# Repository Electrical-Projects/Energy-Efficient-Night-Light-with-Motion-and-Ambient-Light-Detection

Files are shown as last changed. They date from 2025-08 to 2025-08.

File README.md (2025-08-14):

## Energy-Efficient Night-Light with Motion and Ambient-Light Detection
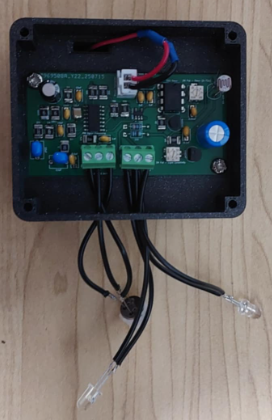
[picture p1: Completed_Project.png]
System Block Diagram


# Description
A simple and affordable motion-activated LED circuit designed for environments where activation should depend on both motion and ambient light levels. The circuit uses a PIR motion sensor and a light-dependent resistor (LDR) to allow users to define the lighting conditions under which motion will trigger the LED. Two onboard potentiometers independently adjust: (1) the environmental light threshold (from full daylight to complete darkness) and (2) the LED on-time delay (0 – 72 seconds). The design is entirely analog, requiring no microcontroller, programming, or complex setup, making it easy to replicate and modify. The circuit is open source under GNU GPL 3.0 and may be freely used, modified, and shared.

# Overview
The system operates by combining PIR motion detection with ambient light sensing. The LDR and potentiometer form an adjustable voltage divider that biases a transistor, determining whether motion detection is enabled based on current light conditions. A TLV8544 low-power comparator stage processes the sensor signals and feeds them into a SN74LVC1G00 NAND gate for signal inversion and logic control before triggering a 555 timer configured in monostable mode. The second potentiometer adjusts the RC time constant of the 555 timer, allowing precise control over the LED on-time from near-instant to over one minute.

Most of the circuit is built with through-hole components for ease of assembly, modification, and long-term serviceability. The PIR sensor section, however, is a compact, self-contained module using mostly SMD components, as it continuously processes and conditions the sensor output — a task that benefits from a smaller, integrated, and more energy-efficient layout.

A series of resistors and filtering capacitors ensure noise immunity and stable operation even in fluctuating lighting or high-EMI environments. Bulk decoupling capacitors stabilize the 6 V nominal supply for reliable performance.

Unlike microcontroller-based solutions, this analog approach offers instant startup, minimal standby current, and long-term reliability without software maintenance. Potential applications include indoor lighting control, battery-powered motion lamps, and outdoor security lights with dusk-to-dawn control.

# Assembly & Modification
All necessary PCB design files, schematics, and a complete Bill of Materials (BOM) are included. Users can order parts directly from the BOM and have the PCB fabricated using the provided Gerber files. The prototype was entirely hand-soldered, using a mix of wire solder for through-hole components and solder paste for select SMD parts in the PIR section. The board includes outputs for two LEDs, allowing for multiple lighting configurations. Since all PCB design files are provided, users are free to modify layouts, adjust footprints, or expand the design for their own applications.

# Enclosure & Use Case
An enclosure design is included, sized to house the PCB and powered by four AAA batteries. In the reference build, this enclosure was used for an indoor novelty night light, shaped like a cat ornament, where the LEDs served as the cat’s eyes

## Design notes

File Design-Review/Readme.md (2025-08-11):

# Project Review – Motion-Activated LED with Adjustable Light Sensitivity & Delay

This folder contains the full technical design review for the motion-activated LED circuit.  
The review covers the complete design process from concept to real-world use, including  
electrical design, mechanical considerations, build steps, testing methodology, and reasoning  
behind every design choice.

All materials are open source. Users can reproduce the project, adapt it to their needs,  
and modify the provided PCB and enclosure files.

---

## Table of Contents

1. [Design Overview & Specifications](01_Design-Overview-Specifications/01_design.md)

---

## How to Navigate

Each section is self-contained and can be read independently, but following them in  
order will give the most complete understanding of the project. The **Design Overview**  
dives into the TLV8544 nanopower op-amp stages, the 3.3 V regulator integration, and  
how the PIR and light-sensitivity controls interface with the delay circuitry.

---

## Related Resources

- [Electrical Design Files](../Electrical-Design)  
- [Mechanical Design Files](../Mechanical-Design)  
- [Main Project README](../README.md)

---

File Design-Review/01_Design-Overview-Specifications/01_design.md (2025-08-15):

# Design Overview & Specifications

## Overview
This board implements an **energy-efficient night light** with:
- **Motion detection** via a PIR sensor.
- **Ambient light gating** so it only triggers under desired lighting conditions.
- **Configurable on-time** using a **low-power CMOS 555** timer.
- **Two LED outputs** for flexible lighting arrangements.
- **No microcontroller** — entirely discrete and inspectable.

**Power:** 4×1.5 V - AAA Batteries (≈6 V)  
**Rails:** 6 V (LEDs only) and 3.3 V (analog front-end + logic + 555).

---

## System Block Diagram

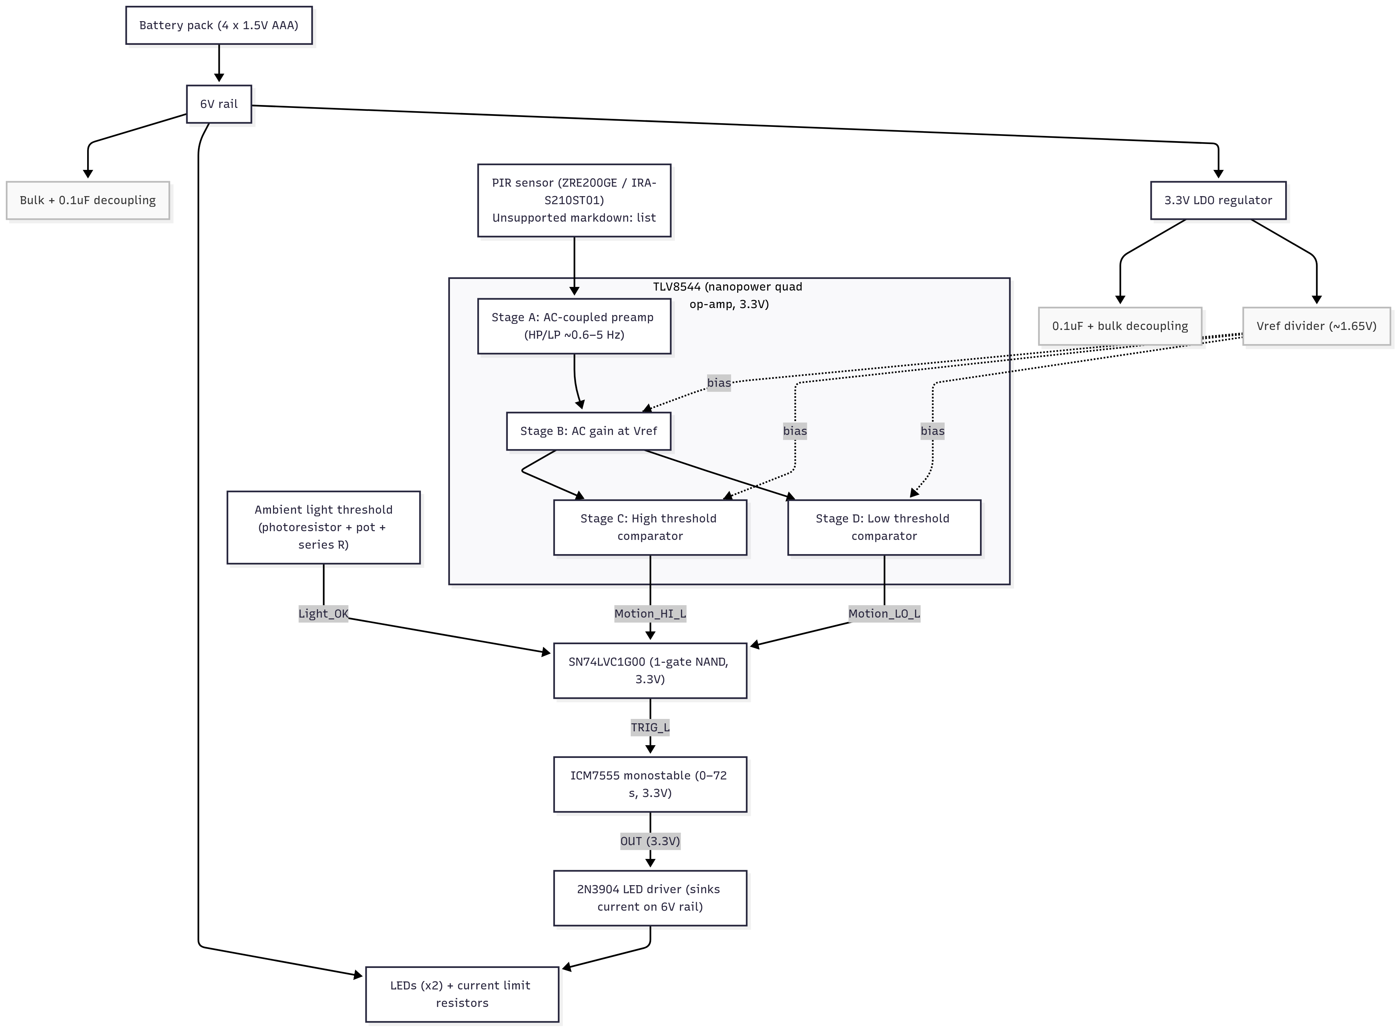
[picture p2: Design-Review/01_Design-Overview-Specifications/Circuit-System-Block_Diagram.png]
System Block Diagram


---

## Key Specifications

| Parameter | Value / Range |
|---|---|
| Supply Voltage |≈6.4 V fresh → 4.4 V depleted
| Rails | 6 V (LEDs only), 3.3 V (AFE/logic/555) |
| Quiescent Current | µA range (TLV8544 + high-value bias) |
| Motion Passband | ≈ 0.6–5 Hz |
| Ambient Light Threshold | Full daylight → full darkness |
| On-Time Range | 0–72 s (adjustable) |
| Outputs | 2× LED headers |
| PIR Lens | Round or inline Fresnel |

---

## Sensors

### PIR Sensor & Optics
- **Sensor:** Dual-element PIR (e.g., Zilog **ZRE200GE** or Murata **IRA-S210ST01**).
- **Lens:** Fresnel (inline or round) creating alternating hot/cold zones to produce AC motion signal.

### Ambient Light Sensor
- **LDR:** CdS photoresistor (e.g., **PDV-P8103**).  
  Dark ≥0.5 MΩ; ~16–33 kΩ @ 10 lux.  
- Divider with 1.5 MΩ fixed + 2 MΩ pot sets adjustable ambient-light threshold.

---

## Power Architecture

- **6 V rail (battery):** Feeds **only** the LED path and the **input** of the LDO.
- **3.3 V rail (LDO):** Feeds **TLV8544**, **ICM7555**, and logic (e.g., SN74LVC1G00).
- **Decoupling:**  
  - 6 V: bulk electrolytic near LED return + 100 nF local.  
  - 3.3 V: 10 µF + 100 nF at the LDO output, 100 nF at each IC.
- **Grounding:** Star from LDO ground; keep LED return currents off the analog ground where possible.

**Why 555 @ 3.3 V?** Lower supply spikes, guaranteed 3.3 V logic levels, and the CMOS 555 (ICM7555) maintains ultra-low supply current. Timing (`t ≈ 1.1RC`) is **independent of supply voltage**.

---

## Analog Front-End (TLV8544, Nanopower)

We use **TLV8544** — a **nanopower**, rail-to-rail quad op-amp — for the PIR chain.

### Stage A — AC Preamp & High-Pass
- Rejects the PIR’s DC output and slow thermal drifts.
- **Passband:** ~0.6–5 Hz.
- **Gain:** ×50–60 (set by feedback and input caps/resistors).

### Stage B — Second Band-Pass & Gain
- Same passband; main amplification.
- **Gain:** ~×50 (total chain ≈ ×2500–×3000).
- Mid-rail bias at **1.65 V** (½·3.3 V) from a high-value divider with local decoupling.

### Stages C & D — Window Comparator (3.3 V)
- Converts the amplified AC into a clean digital motion event.  
- Typical thresholds (vs 3.3 V mid-rail signal):  
  - **Upper:** ≈ **0.84·Vcc** ≈ **2.77 V**  
  - **Lower:** ≈ **0.16·Vcc** ≈ **0.53 V**  
- Outputs feed a small logic gate (NAND/NOR) at **3.3 V** logic level to trigger the 555.

**Why nanopower?** The TLV8544’s ultra-low input bias current (nanoamp to microamp range) minimises standby current draw, extending AAA battery life while maintaining sufficient bandwidth for human motion detection.

The following circuit diagrams illustrate two almost identical signal-processing paths:

1. Top diagram – closely matches the signal processing path implemented in this project.

2. Bottom diagram – represents a special case where the comparator op-amps are intended to be fast and “single-ended” (or “just-pull”) outputs. In this configuration, the op-amp can only source current, and an external pull-down resistor is required for sinking current.

This is not the exact three-stage circuit from the PIR sensor’s datasheet; however, both circuits are functionally very similar, with only minor implementation differences.

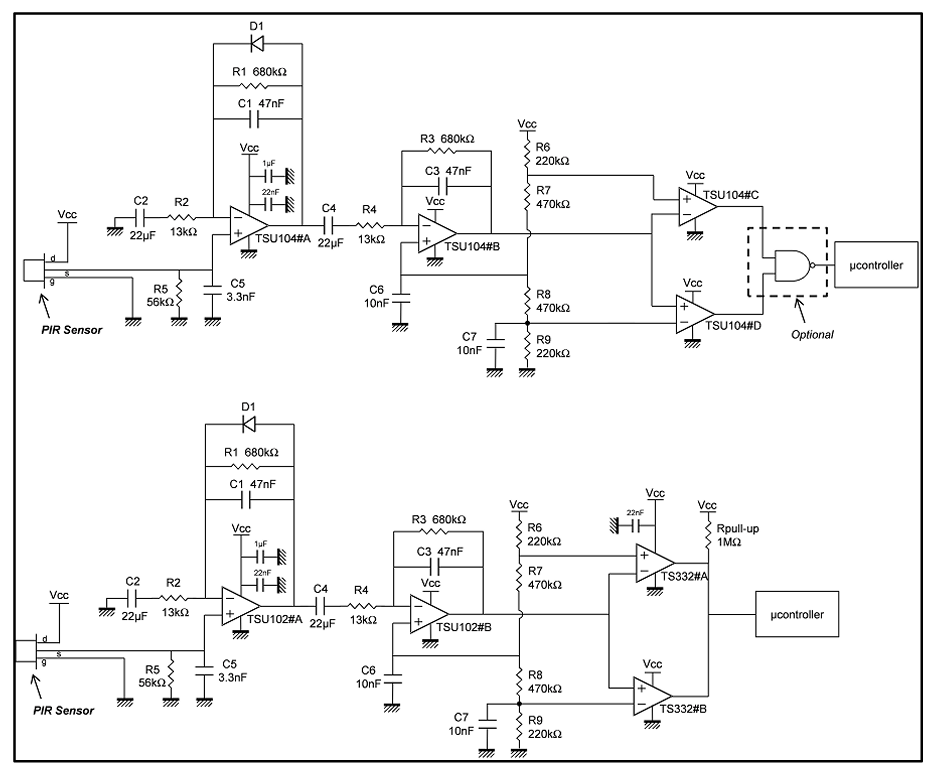
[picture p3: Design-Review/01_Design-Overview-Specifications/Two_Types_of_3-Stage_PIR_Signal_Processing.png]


---

## Ambient Light Gating (3.3 V)
- LDR + 1.5 MΩ + 2 MΩ pot create an adjustable threshold into a 3.3 V comparator/op-amp gate.  
- Motion events are **blocked** unless the ambient light matches the user-set condition (daylight to darkness).

---

## Delay Stage — ICM7555 (CMOS 555 @ 3.3 V)
- **Mode:** Monostable; triggered by motion logic from the window comparator.
- **Timing:**  
  `t_on ≈ 1.1 × R × C`  
  Example: **C = 33 µF**, **Rpot ≈ 0–2 MΩ** → **0–72 s**.
- **Notes:**  
  - Timing is largely independent of supply voltage; running at **3.3 V** improves noise behavior.  
  - Use CMOS 555 (ICM7555) for **low supply current** and **no crowbar spikes**.

The 555 output (3.3 V logic) enables the **LED driver** path that resides on the 6 V rail.

---

## LED Outputs (6 V domain)
- 2× headers with series resistors for direct LED drive from 6 V.  
- Optional low-side NPN/MOSFET if you want higher LED current or multiple LEDs per channel.
- Tie driver **logic input** to the 3.3 V 555 output through a level-safe interface if required (many FET gates are fine; check your specific transistor logic-level specs).

---

## PCB & Layout Notes
- Mostly **through-hole** for easy hand assembly.  
- **SMD** in the PIR front-end to keep high-impedance nodes short and low-noise.  
- Keep PIR input traces short, guard high-impedance nodes, and isolate LED return currents.  
- Place the LDO and 3.3 V decoupling close to the TLV8544 and 555.

---

## Adjustment & Testing
1. Power with fresh AAA cells; verify **6 V** and **3.3 V** rails.  
2. Allow **10–20 s** PIR warm-up.  
3. Set **ambient-light pot** to the desired day/night threshold.  
4. Set **delay pot** for on-time (**0–72 s**).  
5. Walk test across lens zones; confirm clean triggering and LED on-time.

---

## PCB Breakdown

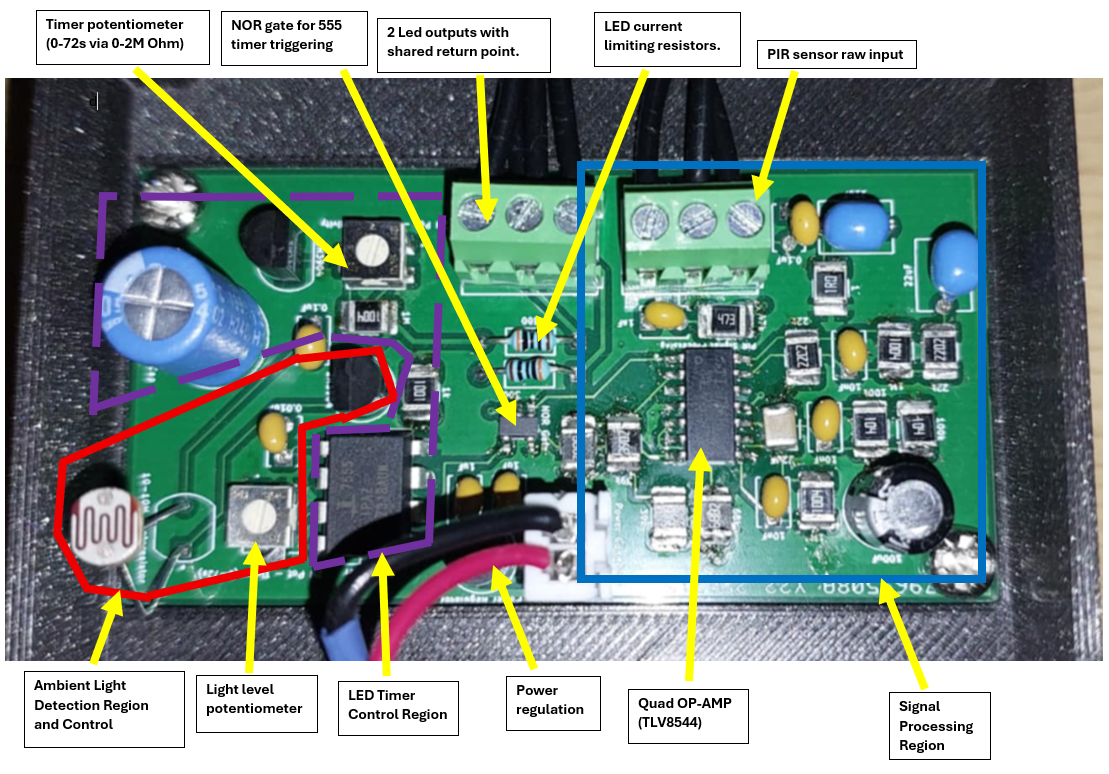
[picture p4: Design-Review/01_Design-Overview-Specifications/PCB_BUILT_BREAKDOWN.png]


---

**Related files:**  
- [Electrical Design](../../Electrical-Design/) — Schematic, BOM.  
- [Mechanical Design](../../Mechanical-Design/) — Enclosure, diffuser.

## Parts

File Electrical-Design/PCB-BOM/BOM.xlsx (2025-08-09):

Index | DigiKey Part # | Manufacturer Part Number | Manufacturer | Description | Quantity | Unit Price | Extended Price
1 | 160-1772-ND | LTW-2R3D7 | Lite-On Inc. | LED WHITE CLEAR T-1 3/4 T/H | 2 | $1.03000 | $2.06
2 | 3314J-205ECT-ND | 3314J-1-205E | Bourns Inc. | TRIMMER 2M OHM 0.25W J LEAD TOP | 2 | $2.53000 | $5.06
3 | S300CACT-ND | RNMF14FTC300R | Stackpole Electronics Inc | RES 300 OHM 1% 1/4W AXIAL | 10 | $0.06900 | $0.69
4 | 296-11597-1-ND | SN74LVC1G02DBVR | Texas Instruments | IC GATE NOR 1CH 2-INP SOT23-5 | 10 | $0.10700 | $1.07
5 | P14480-ND | EEA-GA1A101 | Panasonic Electronic Components | CAP ALUM 100UF 20% 10V RADIAL TH | 3 | $0.51000 | $1.53
6 | 2N3904FS-ND | 2N3904BU | onsemi | TRANS NPN 40V 0.2A TO-92-3 | 3 | $0.45000 | $1.35
7 | 13-RC1210JR-07100KLCT-ND | RC1210JR-07100KL | YAGEO | RES 100K OHM 5% 1/2W 1210 | 10 | $0.05600 | $0.56
8 | 732-2748-ND | 691214110003 | Würth Elektronik | TERM BLK 3POS SIDE ENT 3.5MM PCB | 2 | $1.70000 | $3.40
9 | 490-11915-ND | IRA-S210ST01 | Murata Electronics | MOTION SENSOR | 1 | $3.48000 | $3.48
10 | 490-12568-ND | IML-0685 | Murata Electronics | LENS FOR IRA-S210ST01 | 1 | $4.79000 | $4.79
11 | ICM7555IPAZ-ND | ICM7555IPAZ | Renesas Electronics Corporation | IC OSC SINGLE TIMER 1MHZ 8DIP | 2 | $1.15000 | $2.30
12 | UBW1H330MPD-ND | UBW1H330MPD | Nichicon | CAP ALUM 33UF 20% 50V RADIAL TH | 2 | $1.38000 | $2.76
13 | PDV-P8103-ND | PDV-P8103 | Advanced Photonix | CDS PHOTORESISTOR 16-33KOHM | 1 | $1.12000 | $1.12
14 | 455-B2B-XH-A-ND | B2B-XH-A | JST Sales America Inc. | CONN HEADER VERT 2POS 2.5MM | 2 | $0.16000 | $0.32
15 | 296-51820-1-ND | TLV8544DR | Texas Instruments | IC OPAMP GP 4 CIRCUIT 14SOIC | 2 | $2.35000 | $4.70
16 | 445-173294-1-ND | FG20X7R1C226MRT06 | TDK Corporation | CAP CER 22UF 16V X7R RADIAL | 2 | $1.39000 | $2.78
17 | MCP1702-3302E/TO-ND | MCP1702-3302E/TO | Microchip Technology | IC REG LINEAR 3.3V 250MA TO92-3 | 2 | $1.04000 | $2.08
18 | YAG2296CT-ND | RC1210FR-071KL | YAGEO | RES 1K OHM 1% 1/2W 1210 | 10 | $0.04800 | $0.48
19 | 13-RC1210JR-0747KLCT-ND | RC1210JR-0747KL | YAGEO | RES 47K OHM 5% 1/2W 1210 | 10 | $0.05800 | $0.58
20 | 13-RC1210FR-071MLCT-ND | RC1210FR-071ML | YAGEO | RES 1M OHM 1% 1/2W 1210 | 10 | $0.05100 | $0.51
21 | RMCF1210JT1R00CT-ND | RMCF1210JT1R00 | Stackpole Electronics Inc | RES 1 OHM 5% 1/2W 1210 | 10 | $0.09100 | $0.91
22 | 13-RC1210FR-0722KLCT-ND | RC1210FR-0722KL | YAGEO | RES 22K OHM 1% 1/2W 1210 | 10 | $0.06700 | $0.67
23 | 13-RC1210FR-0739KLCT-ND | RC1210FR-0739KL | YAGEO | RES 39K OHM 1% 1/2W 1210 | 10 | $0.11200 | $1.12
24 | A129893CT-ND | CRGCQ1210F68K | TE Connectivity Passive Product | RES 68K OHM 1% 1/2W 1210 | 10 | $0.18700 | $1.87
25 | 399-13907-1-ND | C315C103K1R5TA7303 | KEMET | CAP CER 10000PF 100V X7R RADIAL | 3 | $1.39000 | $4.17
26 | 399-C318C104Z5U5TA-ND | C318C104Z5U5TA | KEMET | CAP CER 0.1UF 50V Z5U RADIAL | 10 | $0.25500 | $2.55
27 | 399-9714-ND | C315C105K3R5TA | KEMET | CAP CER 1UF 25V X7R RADIAL | 3 | $1.46000 | $4.38
28 | 399-4144-ND | C315C102K1R5TA | KEMET | CAP CER 1000PF 100V X7R RADIAL | 5 | $0.48000 | $2.40
29 | 1276-1851-1-ND | CL32A226MOJNNNE | Samsung Electro-Mechanics | CAP CER 22UF 16V X5R 1210 | 2 | $0.56000 | $1.12
30 | 490-10535-1-ND | GRM32NC81C226KE15L | Murata Electronics | CAP CER 22UF 16V X6S 1210 | 1 | $1.81000 | $1.81

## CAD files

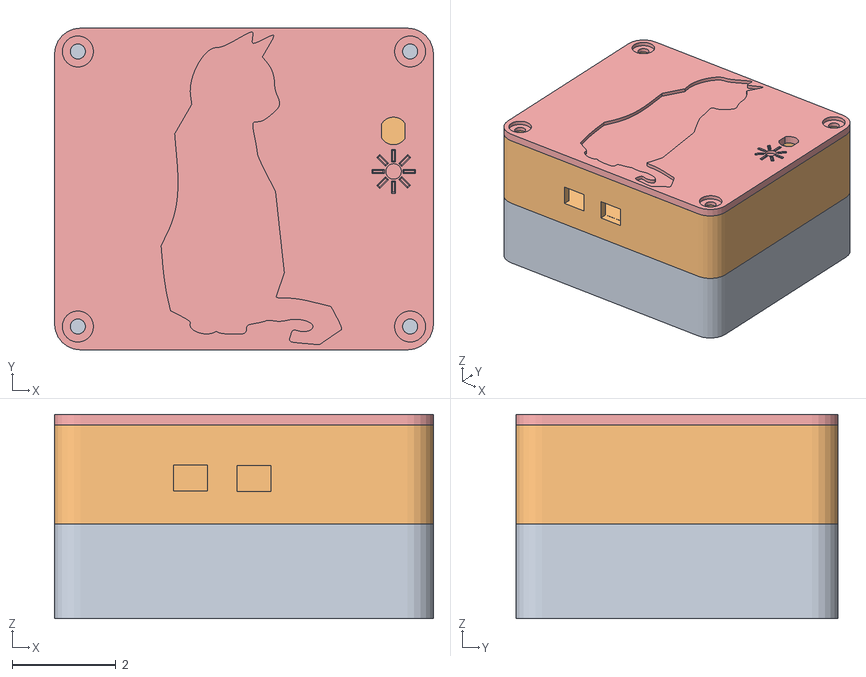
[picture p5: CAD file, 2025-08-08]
Mechanical-Design/Electronics-Enclosure/3D-Enclosure-Models/Night Light Electronics Enclosure_.obj
7.29 x 6.19 x 3.92
Enclosure Base
Enclosure Top
Battery Case Holder
Battery Lid
Enclosure Lid

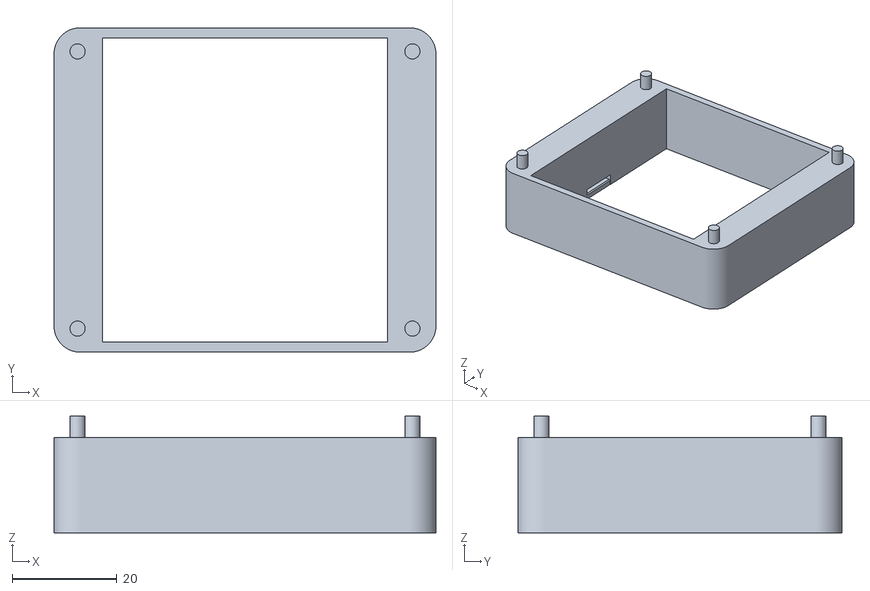
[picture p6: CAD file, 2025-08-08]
Mechanical-Design/Electronics-Enclosure/3D-Printable-STLs/Enclosure Bulk Base.stl
72.9 x 61.9 x 22.3

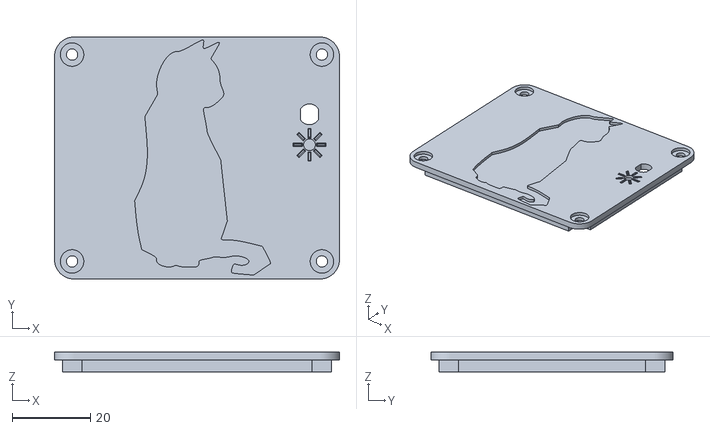
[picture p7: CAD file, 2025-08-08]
Mechanical-Design/Electronics-Enclosure/3D-Printable-STLs/Night Light Electronics Enclosure - LID.stl
72.9 x 61.9 x 5.00

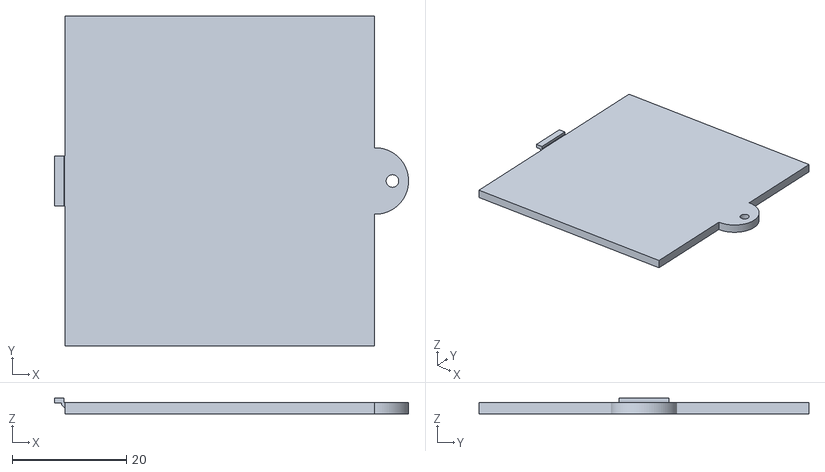
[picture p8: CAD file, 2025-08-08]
Mechanical-Design/Electronics-Enclosure/3D-Printable-STLs/Enclosure Battery Lid.stl
62.0 x 57.7 x 2.75

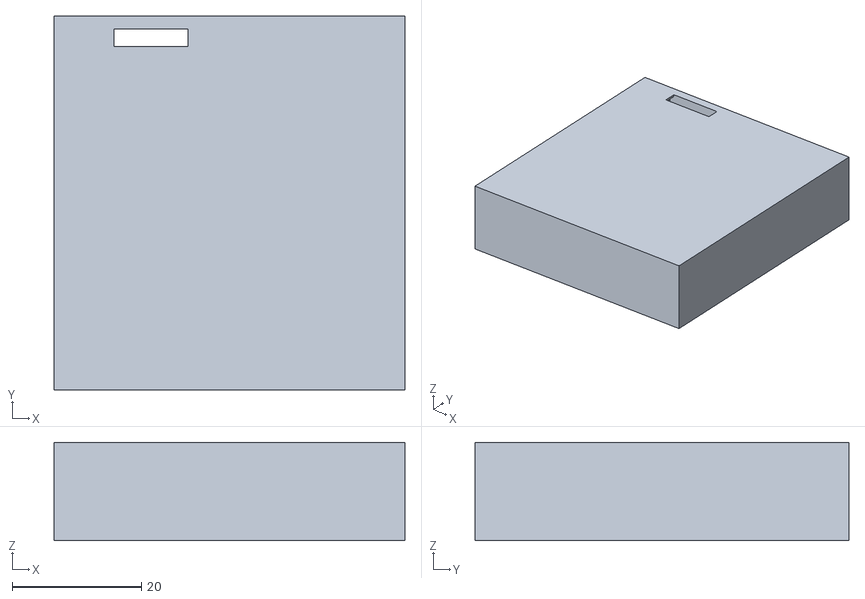
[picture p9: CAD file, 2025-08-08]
Mechanical-Design/Electronics-Enclosure/3D-Printable-STLs/4xAAA Battery Case Holder.stl
54.3 x 57.9 x 15.2

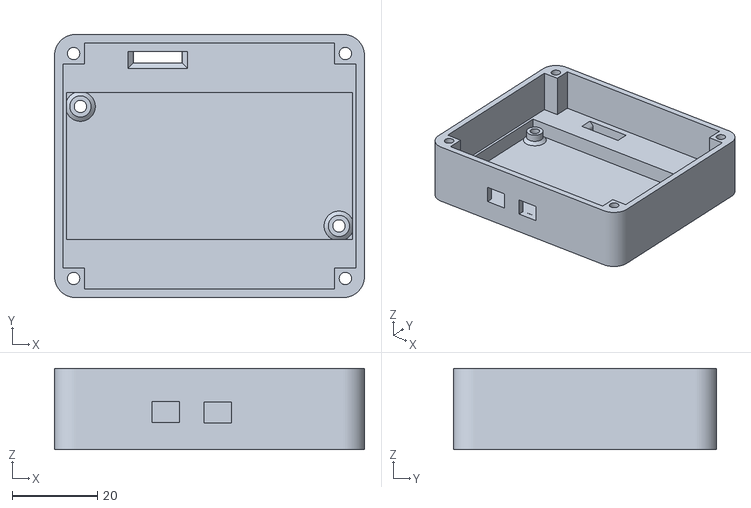
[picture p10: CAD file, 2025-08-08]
Mechanical-Design/Electronics-Enclosure/3D-Printable-STLs/Enclosure Bulk Top.stl
72.9 x 61.9 x 19.0

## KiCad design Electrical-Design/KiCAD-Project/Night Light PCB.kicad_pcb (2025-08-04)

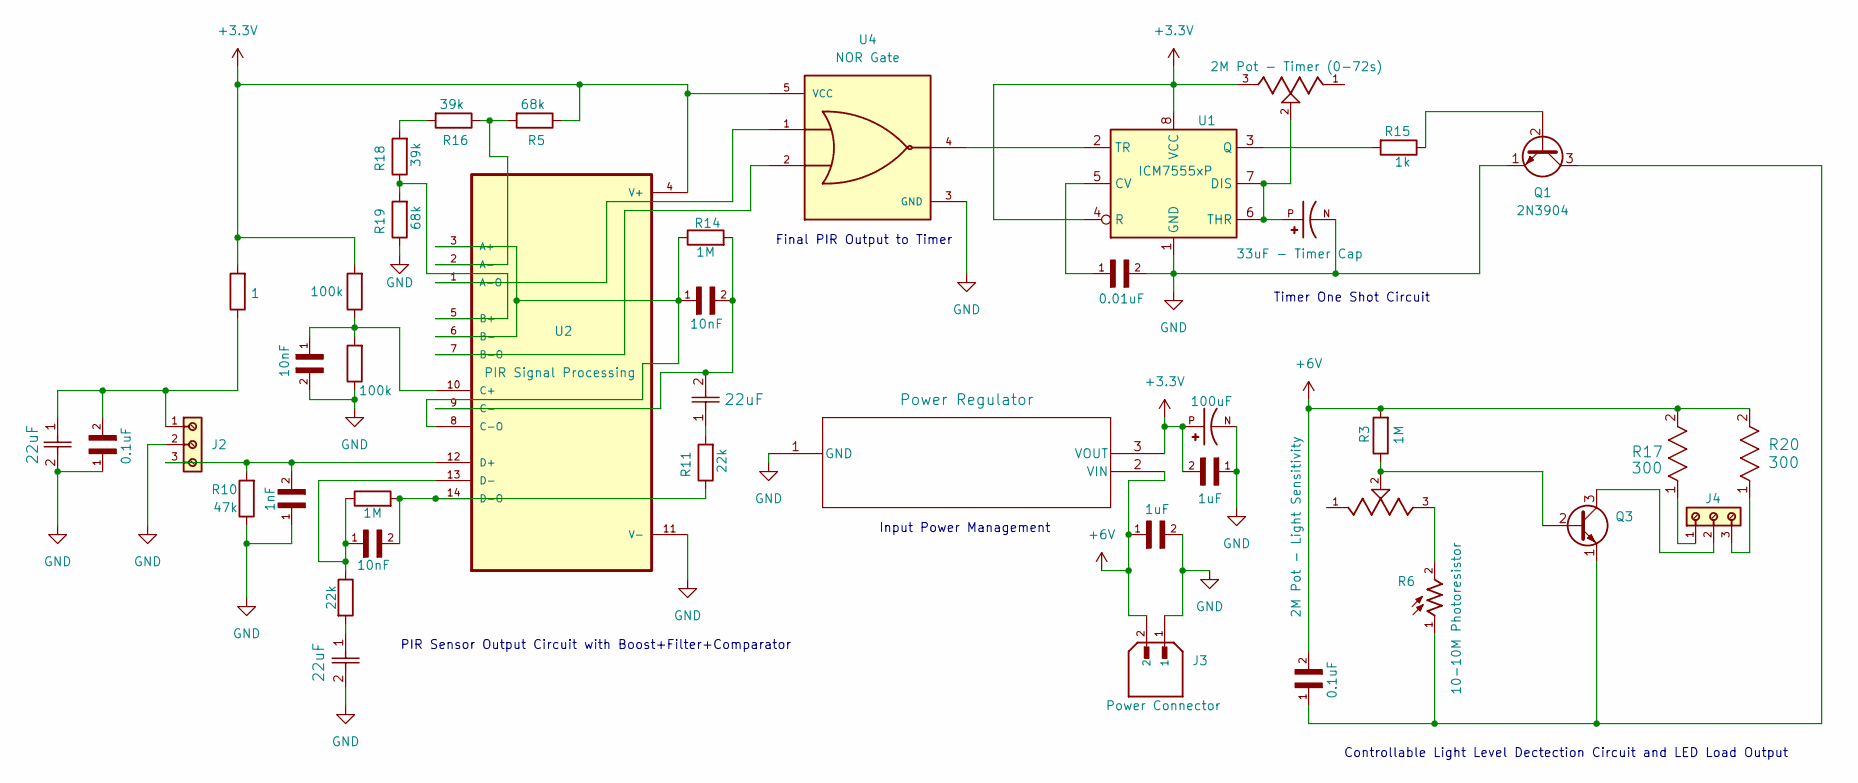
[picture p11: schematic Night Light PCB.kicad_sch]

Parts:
C1: 0.01uF; CAPRR254W54L381T254H466; PARTREV 12/14/2020
C2: 33uF - Timer Cap; CAPPRD350W60D800H1150; PARTREV 20-DEC-19
C3, C11: 22uF; FG20X7R1C226MRT06
C4: 100uF; CAPPRD250W45D630H700; PARTREV 28-FEB-20
C5, C13: 1uF; CAPRR254W54L381T254H466; PARTREV 12/14/2020
C6: 22uF; CAP_CL32_SAM-L
C7, C9, C10: 10nF; CAPRR254W54L381T254H466; PARTREV 12/14/2020
C8, C14: 0.1uF; CAPRR254W54L381T254H466; PARTREV 12/14/2020
C12: 1nF; CAPRR254W54L381T254H466; PARTREV 12/14/2020
J2, J4: 691214110003
J3: Power Connector; JST_B2B-XH-A; PARTREV N/A
Q1, Q3: 2N3904; TO-92_Inline
R3, R12, R14: 1M; R_1210_3225Metric_Pad1.30x2.65mm_HandSolder
R5, R19: 68k; R_1210_3225Metric_Pad1.30x2.65mm_HandSolder
R6: 10-10M Photoresistor; PHODET_PDV-P8103; PARTREV 3/30/06
R7: 1; R_1210_3225Metric_Pad1.30x2.65mm_HandSolder
R8, R9: 100k; R_1210_3225Metric_Pad1.30x2.65mm_HandSolder
R10: 47k; R_1210_3225Metric_Pad1.30x2.65mm_HandSolder
R11, R13: 22k; R_1210_3225Metric_Pad1.30x2.65mm_HandSolder
R15: 1k; R_1210_3225Metric_Pad1.30x2.65mm_HandSolder
R16, R18: 39k; R_1210_3225Metric_Pad1.30x2.65mm_HandSolder
R17, R20: 300; STA_RNMF14_STP
U1: ICM7555xP; DIP-8_W7.62mm
U2: PIR Signal Processing; SOIC127P600X175-14N
U3: Power Regulator; TO-92_MC_MCH
U4: NOR Gate; SOT95P280X145-5N; PARTREV X
VR2: 2M Pot - Timer (0-72s); TRIM_3314J-1-205E
VR3: 2M Pot - Light Sensitivity; TRIM_3314J-1-205E

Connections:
+3.3V: C4.P, C13.2, R5.1, R7.2, R8.2, U1.4 (R), U1.8 (VCC), U2.4 (V+), U3.3 (VOUT), U4.5 (VCC), VR2.3; also elsewhere on the board
+6V: C5.1, C14.2, J3.2, R3.2, R17.2, R20.2, U3.2 (VIN)
GND: C1.2, C2.N, C3.2, C4.N, C5.2, C8.1, C9.2, C11.2, C12.1, C13.1, J2.2, J3.1, Q1.1 (E), R9.1, R10.1, R19.1, U1.1 (GND), U2.11 (V-), U3.1 (GND), U4.3 (GND); also elsewhere on the board
unnamed: C3.1, C8.2, J2.1, R7.1
unnamed: C6.1, R11.2
unnamed: C11.1, R13.2
unnamed: J4.1, R17.1
unnamed: J4.3, R20.1
unnamed: Q1.2 (B), R15.1
unnamed: C14.1, Q1.3 (C), Q3.1 (E), R6.1
unnamed: Q3.2 (B), R3.1, VR3.2
unnamed: J4.2, Q3.3 (C)
unnamed: R6.2, VR3.3
unnamed: R16.2, R18.2
unnamed: C1.1, U1.5 (CV)
unnamed: C2.P, U1.6 (THR), U1.7 (DIS), VR2.2
unnamed: R15.2, U1.3 (Q)
unnamed: U1.2 (TR), U4.4
unnamed: C10.1, R14.1, U2.3 (A+), U2.6 (B-), U2.8 (C-O)
unnamed: R5.2, R16.1, U2.2 (A-)
unnamed: U2.1 (A-O), U4.1
unnamed: R18.1, R19.2, U2.5 (B+)
unnamed: U2.7 (B-O), U4.2
unnamed: C9.1, R8.1, R9.2, U2.10 (C+)
unnamed: C6.2, C10.2, R14.2, U2.9 (C-)
unnamed: C12.2, J2.3, R10.2, U2.12 (D+)
unnamed: C7.1, R12.1, R13.1, U2.13 (D-)
unnamed: C7.2, R11.1, R12.2, U2.14 (D-O)

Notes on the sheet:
PIR Sensor Output Circuit with Boost+Filter+Comparator
Controllable Light Level Dectection Circuit and LED Load Output
Final PIR Output to Timer
Input Power Management
Timer One Shot Circuit

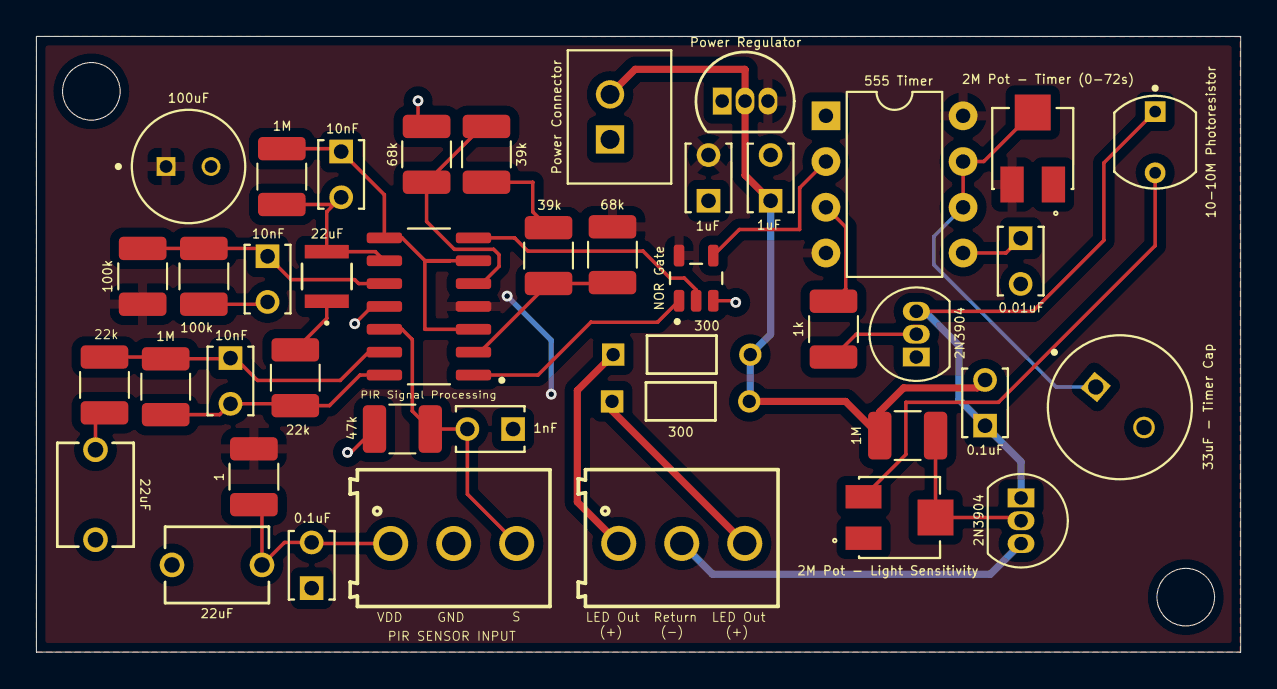
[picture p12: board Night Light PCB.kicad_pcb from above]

Board: 2 copper layers, 66.9 x 34.2 mm, 42 parts (0 on the bottom side), 28 nets.

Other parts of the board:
100uF: EEAGA1A101; CAPPRD250W45D630H700

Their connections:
+3.3V: 100uF.P; also elsewhere on the board
GND: 100uF.N; also elsewhere on the board
